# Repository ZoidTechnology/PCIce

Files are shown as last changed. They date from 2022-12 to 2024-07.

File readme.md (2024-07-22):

# PCIce
A PCI Express card with an inbuilt PWM fan controller and mounting points for an 80mm fan.

PCIce is available to buy on [Tindie](https://www.tindie.com/products/code7/pcice/).  
More information can be found on my [website](https://zoid.com.au/pcice/).
## Hardware
The hardware is based on an ATtiny13A which outputs a 25kHz PWM signal to the fan. A button is used for speed control, and the current speed is displayed on four multiplexed LEDs.
## Firmware
### Functionality
The firmware attempts to load the speed setting from EEPROM on boot. The speed setting is stored twice to guard against corruption. The second copy is inverted to detect a blank EEPROM. The speed will default to maximum if corruption is detected to prevent overheating. The button is debounced in software and must be released for a short period before the next press is registered.
### Building
The firmware can be compiled and flashed with the `build` script inside the firmware directory. This script expects an AVRISP MKII to be connected over USB. `avr-gcc`, `avr-objcopy`, `avrdude` and `avr-libc` are required to build the firmware.
## License
PCIce is licensed under the GNU GPLv3 license. This license does not cover the use of Zoid Technology trademarks. A list of trademarks can be found [here](https://zoid.com.au/trademarks/).

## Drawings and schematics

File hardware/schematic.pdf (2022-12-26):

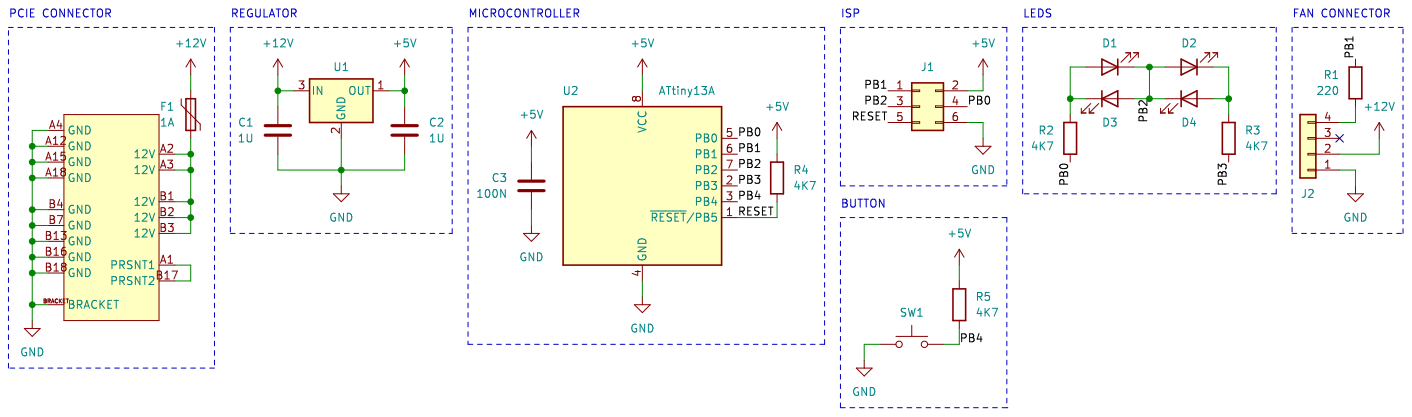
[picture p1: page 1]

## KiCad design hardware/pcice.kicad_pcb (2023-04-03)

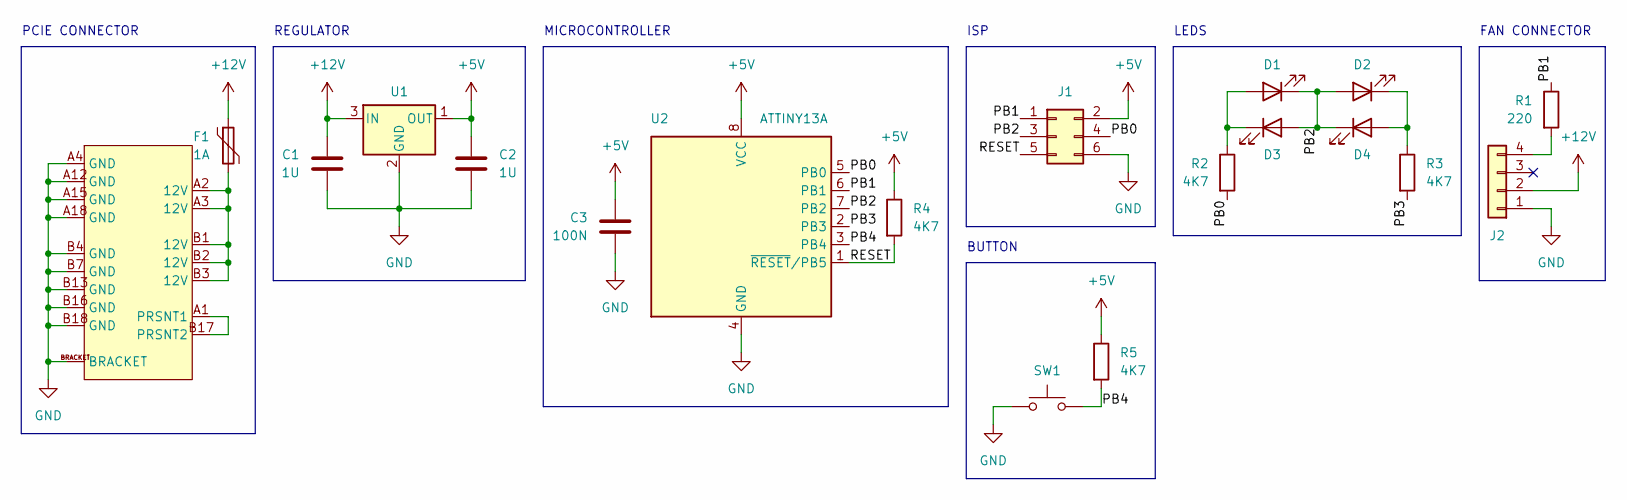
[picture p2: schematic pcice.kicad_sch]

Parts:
C1, C2: 1U; C_0805
C3: 100N; C_0805
D1, D2, D3, D4: LED; LED_0805
F1: 1A; F_1812
J1: CON 2X3; GENERIC_IDC_2X3
J2: CON 3+1; 744-81-04TB1B
J3: PCIE X1 12V; PCIE_X1_12V
R1: 220; R_0805
R2, R3, R4, R5: 4K7; R_0805
SW1: LPTS; GENERIC_LOW_PROFILE_SWITCH
U1: 5V SOT-89 REG; SOT89-3
U2: ATTINY13A; SOIC-8

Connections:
+5V: C2.1, C3.1, J1.2, R4.1, R5.1, U1.1 (OUT), U2.8 (VCC)
+12V: C1.1, F1.1, J2.2, U1.3 (IN)
/PB0: J1.4, R2.2, U2.5 (PB0)
/PB1: J1.1, R1.1, U2.6 (PB1)
/PB2: D1.1 (K), D2.2 (A), D3.2 (A), D4.1 (K), J1.3, U2.7 (PB2)
/PB3: R3.2, U2.2 (PB3)
/PB4: R5.2, SW1.2, U2.3 (PB4)
/RESET: J1.5, R4.2, U2.1 (~RESET/PB5)
GND: C1.2, C2.2, C3.2, J1.6, J2.1, J3.A4 (GND), J3.A12 (GND), J3.A15 (GND), J3.A18 (GND), J3.B4 (GND), J3.B7 (GND), J3.B13 (GND), J3.B16 (GND), J3.B18 (GND), J3.BRACKET, SW1.1, U1.2 (GND), U2.4 (GND)
unnamed: D1.2 (A), D3.1 (K), R2.1
unnamed: D2.1 (K), D4.2 (A), R3.1
unnamed: F1.2, J3.A2 (12V), J3.A3 (12V), J3.B1 (12V), J3.B2 (12V), J3.B3 (12V)
unnamed: J2.4, R1.2
unnamed: J3.A1 (PRSNT1), J3.B17 (PRSNT2)

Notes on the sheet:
REGULATOR
MICROCONTROLLER
FAN CONNECTOR
PCIE CONNECTOR
LEDS
ISP
BUTTON

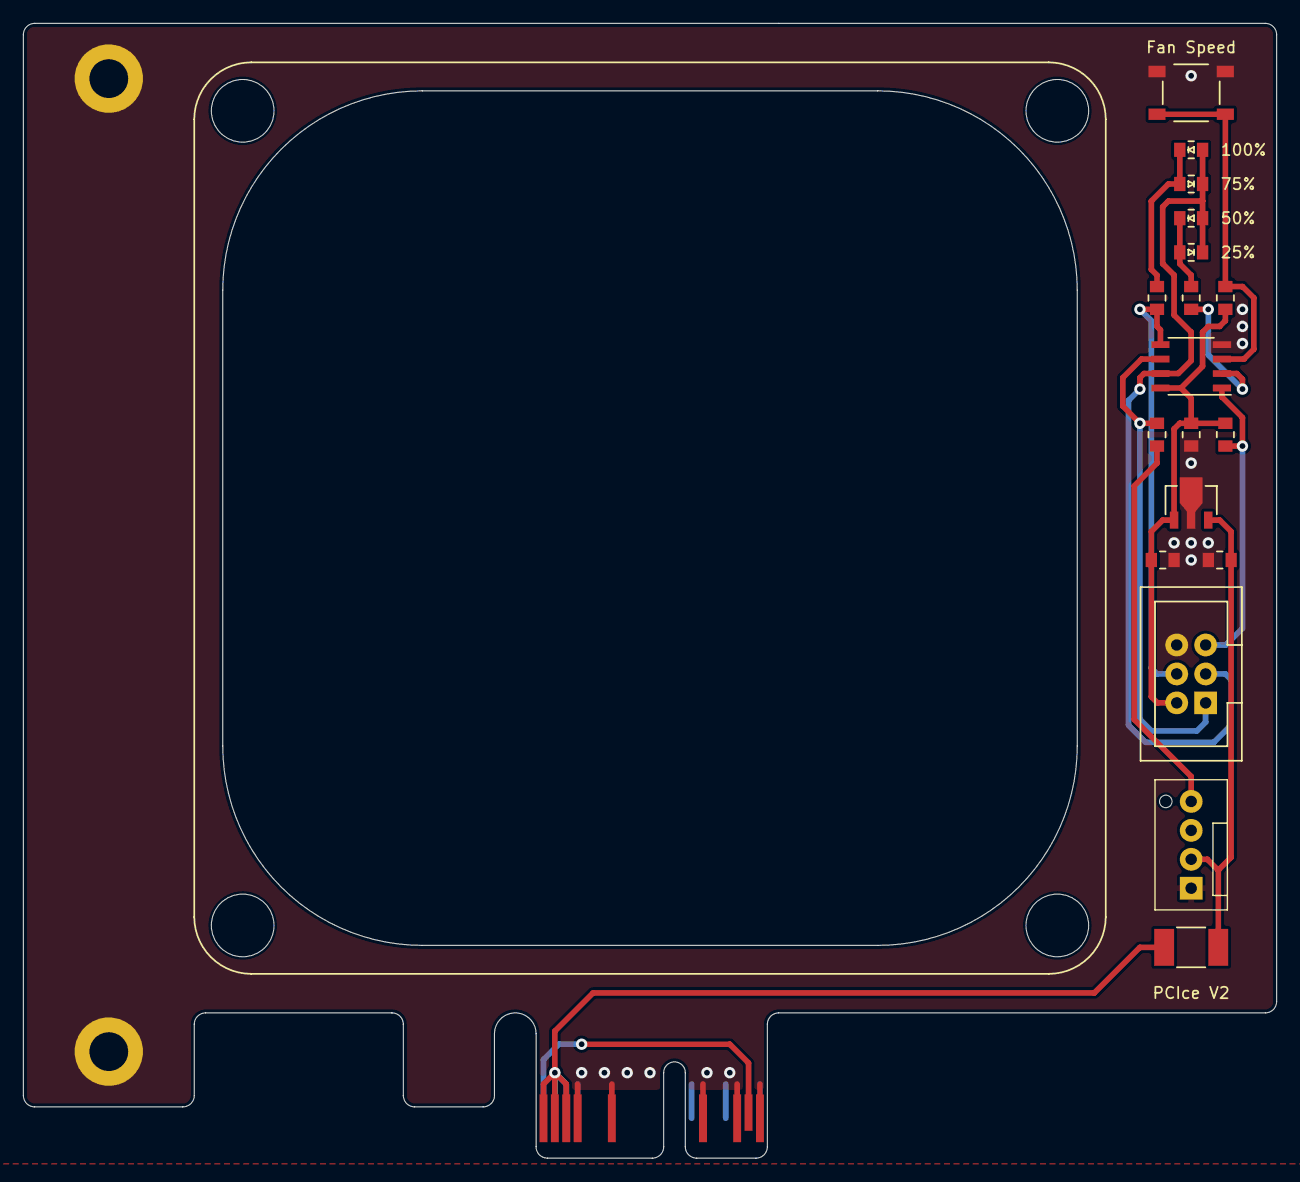
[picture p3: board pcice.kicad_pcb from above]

Board: 2 copper layers, 110.0 x 99.6 mm, 19 parts (0 on the bottom side), 14 nets.

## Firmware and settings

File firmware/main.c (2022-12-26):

#include <avr/io.h>
#include <avr/eeprom.h>

#define SPEED_ADDRESS ((uint8_t*) 0)
#define SPEED_COMPLIMENT_ADDRESS ((uint8_t*) 1)
#define MAX_SPEED 3
#define DEBOUNCE_DELAY 4096

const uint8_t DISPLAY[] = {0x08, 0x05, 0x01, 0x0C};

int main()
{
	DDRB = 0x0F; // Set B0-B3 as outputs

	OCR0A = 47; // Set top value for counter (9.6 MHz / 8 / 25 kHz - 1)

	TCCR0A = 0x23; // Use fast PWM mode with OCR0A as maximum and positive polarity for OC0B
	TCCR0B = 0x09; // Enable timer without prescaler

	uint8_t speed = eeprom_read_byte(SPEED_ADDRESS);

	if ((uint8_t) ~speed != eeprom_read_byte(SPEED_COMPLIMENT_ADDRESS))
	{
		speed = MAX_SPEED; // Use maximum speed as a fallback if the EEPROM is corrupt
	}

	while (1)
	{
		PORTB = DISPLAY[speed];

		OCR0B = 11 + 12 * speed; // Set output compare to approximation of speed as a percentage of 47
		
		uint16_t delay = DEBOUNCE_DELAY;

		while (1)
		{
			if (PINB & 0x10)
			{
				if (delay)
				{
					delay--;
				}
			}
			else
			{
				if (!delay)
				{
					if (++speed > MAX_SPEED)
					{
						speed = 0;
					}

					eeprom_write_byte(SPEED_ADDRESS, speed);
					eeprom_write_byte(SPEED_COMPLIMENT_ADDRESS, ~speed);

					break;
				}

				delay = DEBOUNCE_DELAY;
			}
		}
	}
}

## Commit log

2023-03-03 Enable BOD to prevent unintended behaviour at low voltages
2023-04-03 Added hardware files
    [pcice.kicad_pcb, pcice.kicad_sch]
